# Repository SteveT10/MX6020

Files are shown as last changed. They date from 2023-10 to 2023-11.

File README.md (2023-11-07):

# MX60 + 20

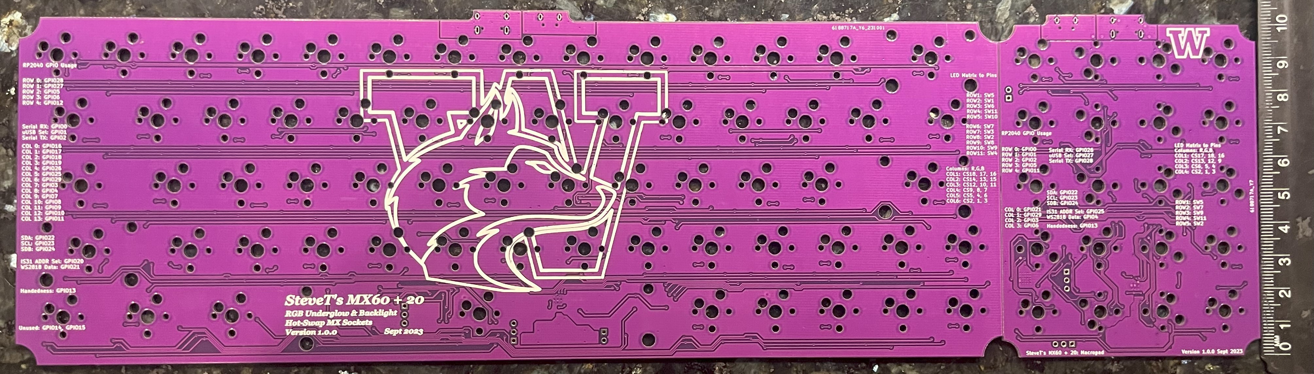
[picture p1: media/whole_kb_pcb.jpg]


The MX60 + 20 is a 60% keyboard PCB that features Hot-Swappable MX Switches, RGB underglow, RGB backlighting, and a dettachable 4x5 macropad via micro-usb male to male. The hardware was designed in Kicad by myself and uses QMK firwmare.

## Design Specifications:
Main body:
- Modified ANSI 60% layout
    - Shrank 2.25u shift down to 2u shift key.
    - Extra 1u key added on second to bottom row.
    - 64 Keys total.
- 8 WS2812 ARGBs for underglow
- 64 RGB Backlights
- USB-C Connecter to PC.
- Micro-USB Connecter to macropad.
- 288.8 mm by 104 mm PCB size.
- 2 Layer PCB

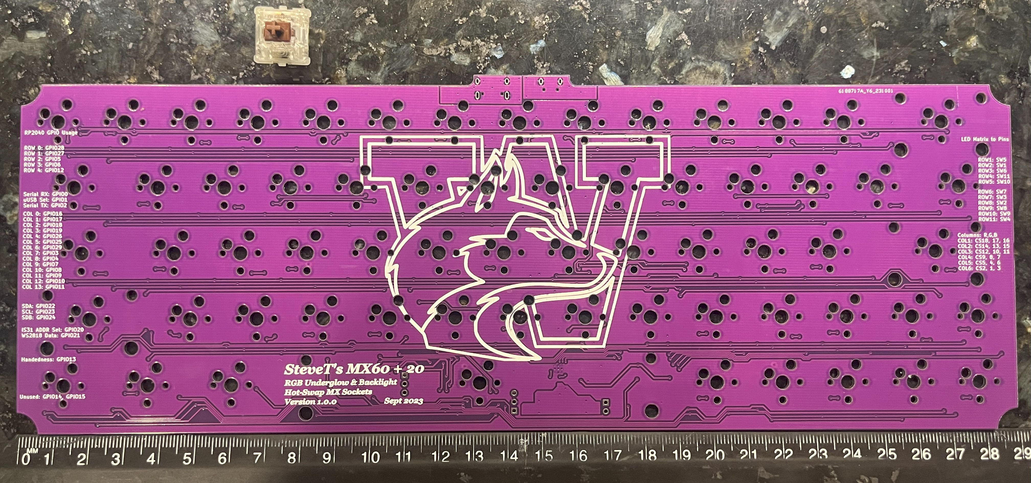
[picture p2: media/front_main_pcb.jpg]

Front side of main body PCB.

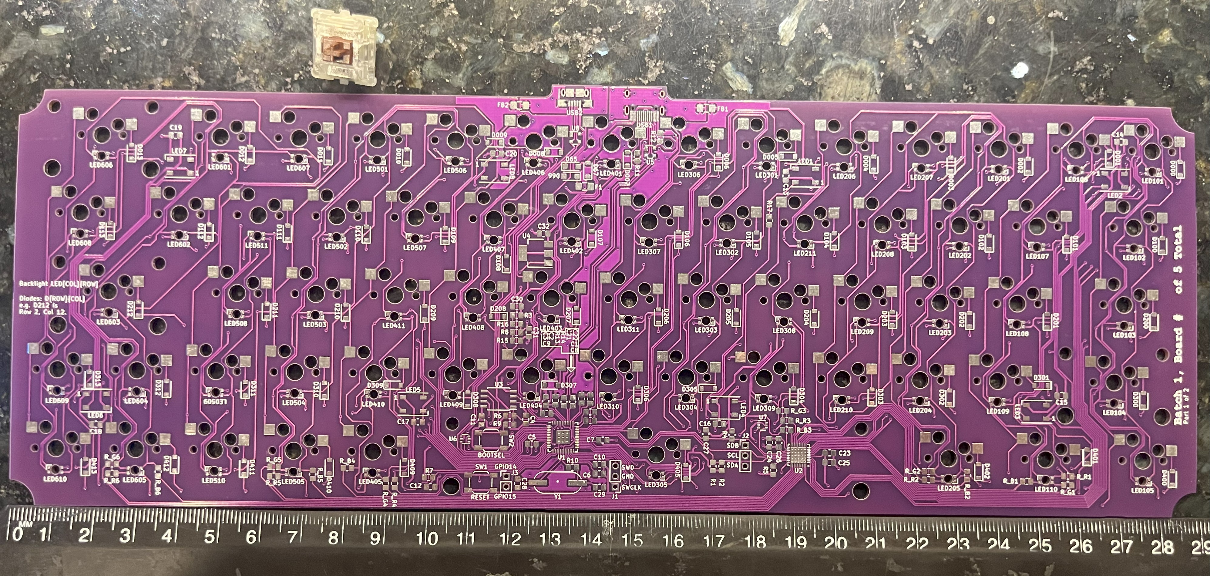
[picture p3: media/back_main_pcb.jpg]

Back side of main body PCB.

Macropad:
- 4x5 layout
    - 20 keys total.
- 4 WS2812 ARGBs for underglow.
- 20 RGB backlights.
- USB-C Connecter to PC.
- Micro-USB Connecter to main body.
- 79 mm by 104 mm PCB size.
- 2 Layer PCB

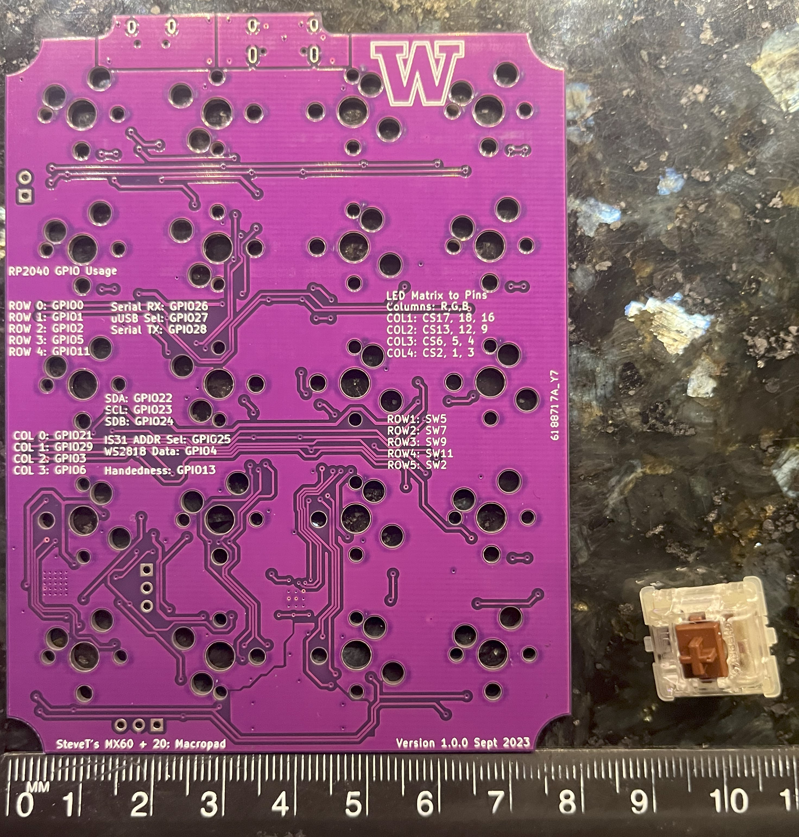
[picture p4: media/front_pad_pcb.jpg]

Front side of macro pad PCB.

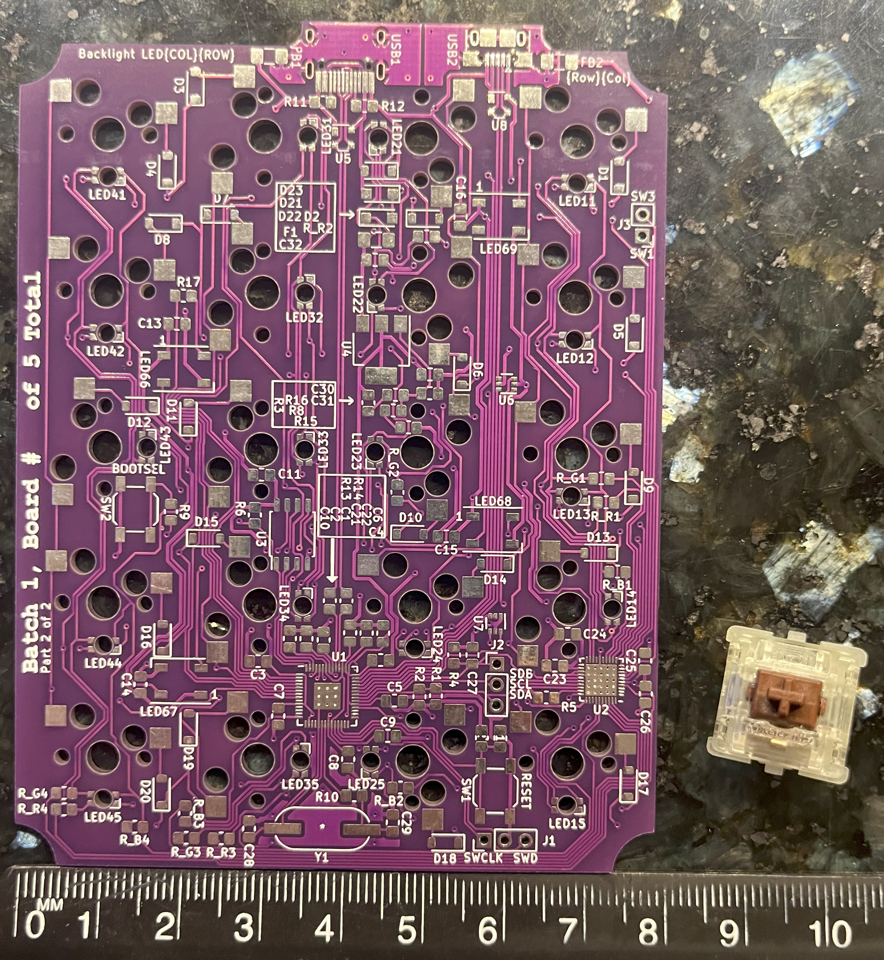
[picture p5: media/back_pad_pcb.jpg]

Back side of macro pad PCB.

## Goal
This project's overall goal is to act as a progressive learning project that complements my education in Computer Engineering. The first goal of this project was to familiarize myself with hardware design, where I would learn: 
- How to design circuit schematics and PCB layout in EDA software, specifically KiCad.
- How to use 3D printers and CAD software to design keycaps and cases
- How to use tools such reflow ovens, stencils, and soldering paste to assemble electronics.

<p>After verifying my hardware design and solving any potential issues, I would move onto the second goal of this project which is learn more about firmware, more specifically:</p>

- How to program C/Assembly in ARM-based MCU.
- How communication protocals such as I2C are implemented.
- More to come! (As I have not gotten to this stage yet)

## Creating Gerbers
Most PCB fabrication places expect gerber files. Gerber files describe the layout of pads, traces, drill holes, and other geometry for each layer on the PCB. Gerber files should be uploaded in a compress zip file containing all layers. To create gerber files in KiCad v7.0:

1. Open KiCad's PCB viewer
2. Go to `File` -> `Plot`
3. Select layers and options accordingly to your fabrication shop's settings. I chose JLCPCB so I set the following options below and set all others to unchecked.
    * Include Layers:
        * F.Cu
        * B.Cu
        * F.Paste
        * B.Paste
        * F.Silkscreen
        * B.Silkscreen
        * F.Mask
        * B.Mask
        * Edge.cuts
    * `Plot reference designators`
    * `Plot footprint values`
    * `Use Protel filename extensions`
    * `Subtract soldermask from silkscreen`
    * Check zone fills before plotting.
4. Set the output directory to `project-name-gerbers`, where project name is a placeholder.
5. Click `Plot` to generate layer gerbers.
6. Click `Generate Drill files...`
7. Again, select options that match with your fabrication shop's specifications. For JLCPCB, this is:
    * Drill File Format set to Excellon.
    * Oval Holes Drill Mode is set to `Use alternate drill mode`
    * Map File Format set to `Gerber`
    * Drill Origin set to `Absolute`
    * Drill units set to `Millimeters`
    * Zeros format set to `Decimal format`
8. Click `Generate Drill File`
9. Zip up your gerber files and now it is ready for upload.

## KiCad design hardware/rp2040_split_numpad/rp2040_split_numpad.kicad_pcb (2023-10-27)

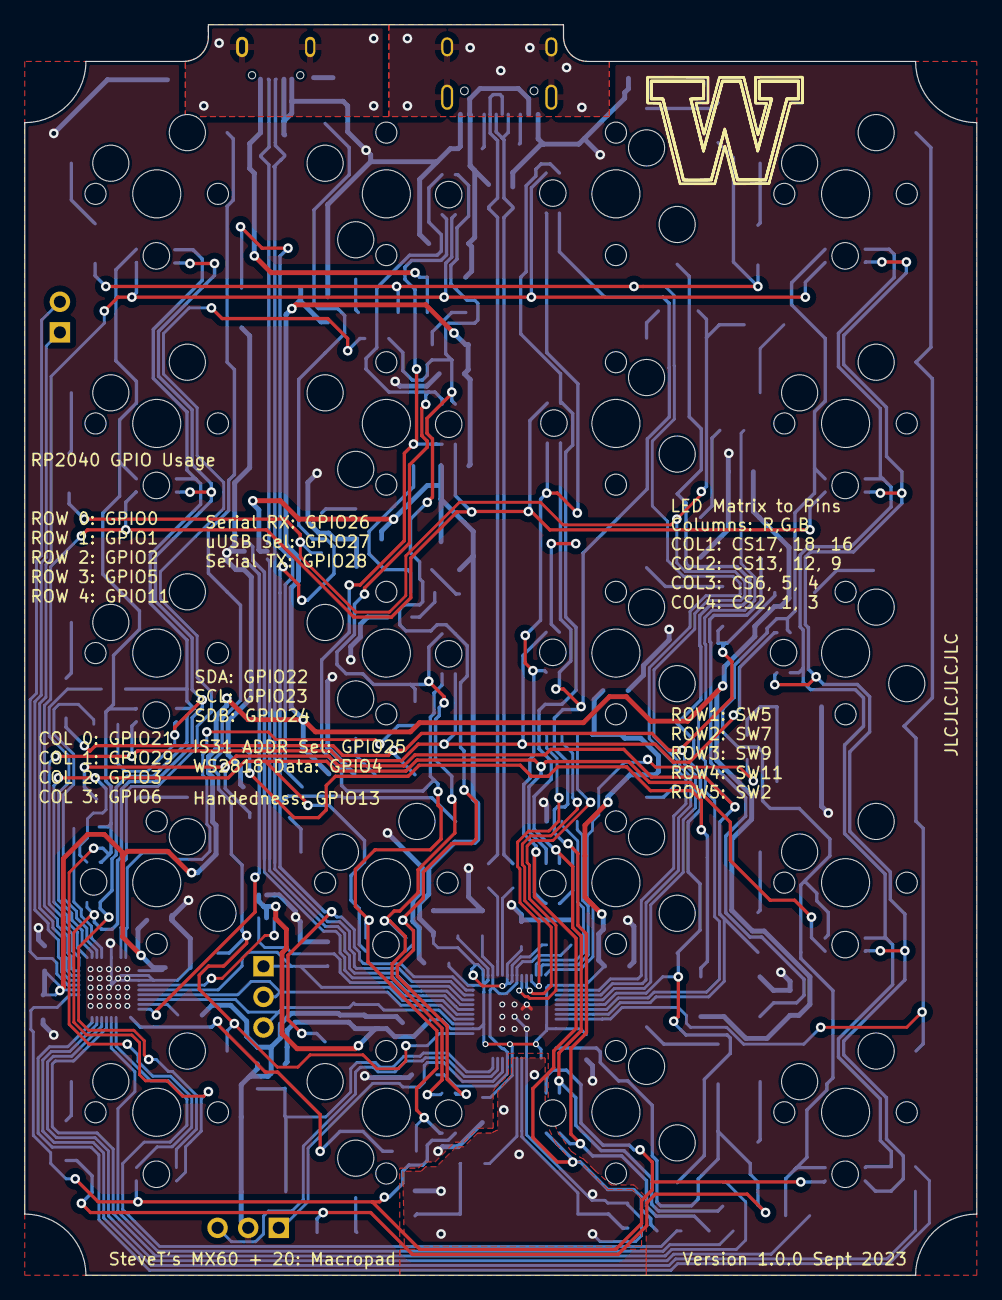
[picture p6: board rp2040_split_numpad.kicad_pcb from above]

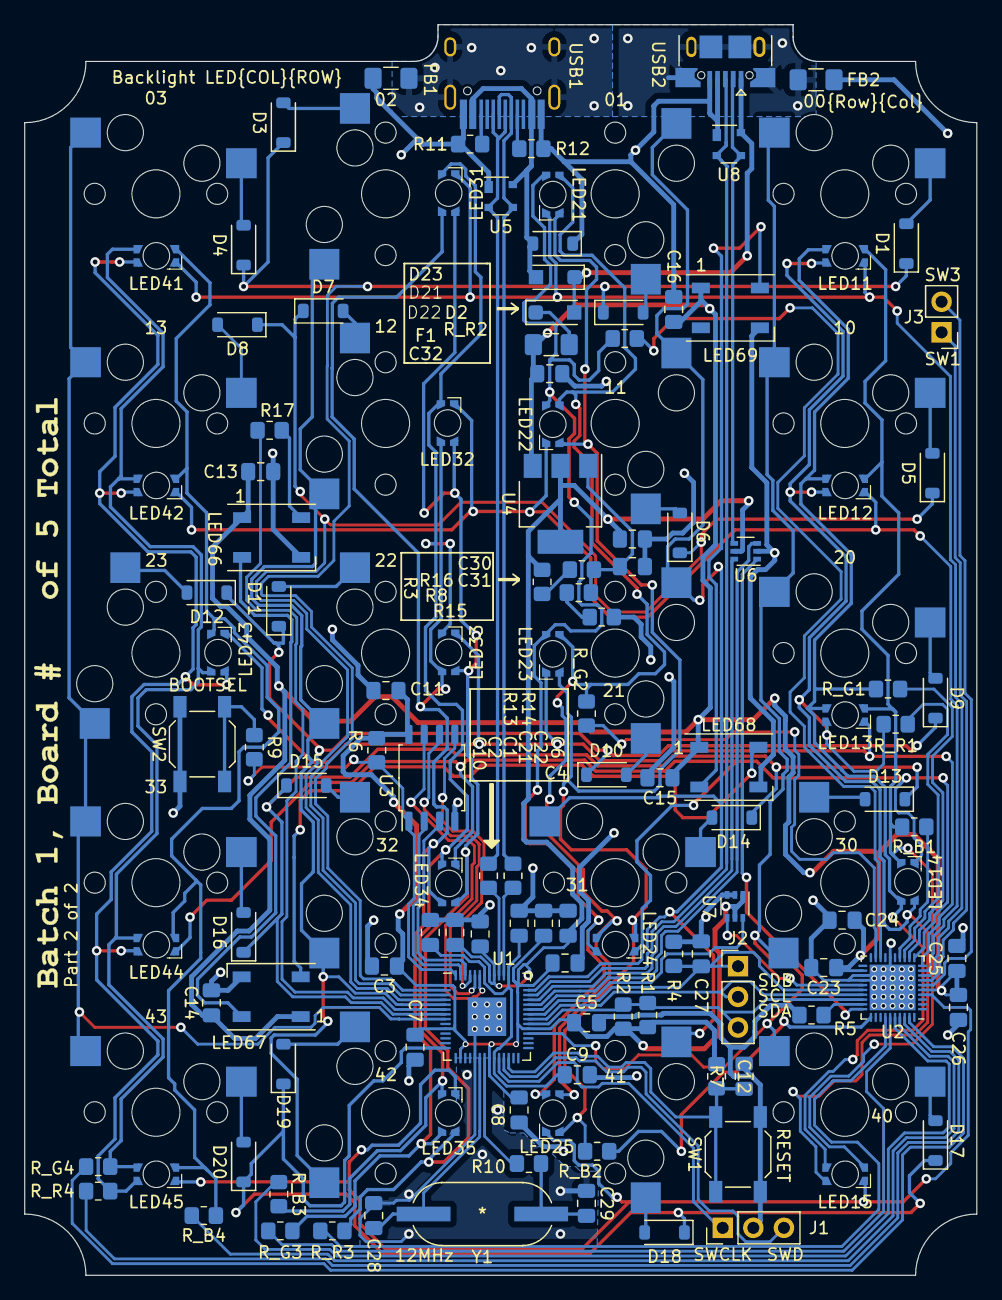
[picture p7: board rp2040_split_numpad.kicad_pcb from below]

Board: 2 copper layers, 79.0 x 103.8 mm, 143 parts (123 on the bottom side), 107 nets.

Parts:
C1, C2, C3, C4, C5, C6, C7, C8, C9, C10, C11, C12, C13, C14, C15, C16: 100n; C_0805_2012Metric_Pad1.18x1.45mm_HandSolder
C21, C22, C23, C24: 1u; C_0805_2012Metric_Pad1.18x1.45mm_HandSolder
C25, C26, C27: 0.1u; C_0805_2012Metric_Pad1.18x1.45mm_HandSolder
C28, C29: 27p; C_0805_2012Metric_Pad1.18x1.45mm_HandSolder
C30, C31, C32: 10u; C_0805_2012Metric_Pad1.18x1.45mm_HandSolder
D1, D2, D3, D4, D5, D6, D7, D8, D9, D10, D11, D12, D13, D14, D15, D16, D17, D18, D19, D20: D_Small; D_SOD-123
D21, D22: D_Schottky; D_SOD-123FL
D23: D_TVS; D_SOD-123
F1: 500m; Fuse_1206_3216Metric_Pad1.42x1.75mm_HandSolder
FB1, FB2: 60@100Mhz; L_1206_3216Metric_Pad1.42x1.75mm_HandSolder
J1, J2: Conn_01x03; PinHeader_1x03_P2.54mm_Vertical
J3: Conn_01x02; PinHeader_1x02_P2.54mm_Vertical
K1: 00; MXOnly-1U-Hotswap
K2: 01; MXOnly-1U-Hotswap
K3: 02; MXOnly-1U-Hotswap
K4: 03; MXOnly-1U-Hotswap
K5: 10; MXOnly-1U-Hotswap
K6: 11; MXOnly-1U-Hotswap
K7: 12; MXOnly-1U-Hotswap
K8: 13; MXOnly-1U-Hotswap
K9: 20; MXOnly-1U-Hotswap
K10: 21; MXOnly-1U-Hotswap
K11: 22; MXOnly-1U-Hotswap
K12: 23; MXOnly-1U-Hotswap
K13: 30; MXOnly-1U-Hotswap
K14: 31; MXOnly-1U-Hotswap
K15: 32; MXOnly-1U-Hotswap
K16: 33; MXOnly-1U-Hotswap
K17: 40; MXOnly-1U-Hotswap
K18: 41; MXOnly-1U-Hotswap
K19: 42; MXOnly-1U-Hotswap
K20: 43; MXOnly-1U-Hotswap
LED11, LED12, LED13, LED14, LED15, LED21, LED22, LED23, LED24, LED25, LED31, LED32, LED33, LED34, LED35, LED41, LED42, LED43, LED44, LED45: LED_RAGB; LED__RBG_1206_3216Metric_ReverseMount_Hole2.2x2.2mm
LED66, LED67, LED68, LED69: WS2812B; LED_WS2812B_PLCC4_5.0x5.0mm_P3.2mm
R1, R2, R3: 2k; R_0805_2012Metric_Pad1.20x1.40mm_HandSolder
R4: 100k; R_0805_2012Metric_Pad1.20x1.40mm_HandSolder
R5, R6, R7: 10k; R_0805_2012Metric_Pad1.20x1.40mm_HandSolder
R8, R9, R10: 1k; R_0805_2012Metric_Pad1.20x1.40mm_HandSolder
R11, R12: 5.1k; R_0805_2012Metric_Pad1.20x1.40mm_HandSolder
R13, R14: 27; R_0805_2012Metric_Pad1.20x1.40mm_HandSolder
R15, R16, R17: 500; R_0805_2012Metric_Pad1.20x1.40mm_HandSolder
R_B1, R_B2, R_B3, R_B4: 20; R_0805_2012Metric_Pad1.20x1.40mm_HandSolder
R_G1, R_G2, R_G3, R_G4: 20; R_0805_2012Metric_Pad1.20x1.40mm_HandSolder
R_R1, R_R2, R_R3, R_R4: 51; R_0805_2012Metric_Pad1.20x1.40mm_HandSolder
SW1: Reset; SW_SPST_SKQG_WithStem
SW2: Boot; SW_SPST_SKQG_WithStem
U1: RP2040; QFN-56-1EP_7x7mm_P0.4mm_EP3.2x3.2mm
U2: IS31FL3743A-QULS4-TR; UQFN-40-1EP_5x5mm_P0.4mm_EP3.8x3.8mm
U3: W25Q32JVSS; SOIC-8_5.23x5.23mm_P1.27mm
U4: NCP1117-ADJ_SOT223; SOT-223-3_TabPin2
U5, U8: PRTR5V0U2X; SOT-143
U6, U7: BL1551B; SOT-363_SC-70-6
USB1: HRO-TYPE-C-31-M-12; HRO-TYPE-C-31-M-12-HandSoldering
USB2: USB_B_Micro; USB_Micro-B_XKB_U254-051T-4BH83-F1S
Y1: 12MHz; ABLS-12.000MHZ-B4-T

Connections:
+1V1: C9.1, C10.1, C21.1, U1.23 (DVDD), U1.45 (VREG_VOUT), U1.50 (DVDD)
+3.3V: C1.1, C2.1, C3.1, C4.1, C5.1, C6.1, C7.1, C8.1, C11.1, C22.1, C30.1, R1.1, R2.1, R3.1, R6.1, R7.1, U1.1 (IOVDD), U1.10 (IOVDD), U1.16 (GPIO13), U1.22 (IOVDD), U1.33 (IOVDD), U1.42 (IOVDD), U1.43 (ADC_AVDD), U1.44 (VREG_IN), U1.48 (USB_VDD), U1.49 (IOVDD), U3.8 (VCC), U4.2 (VO), U6.5 (V+), U7.1, U7.5 (V+)
+5V: C13.1, C14.1, C15.1, C16.1, C23.1, C24.1, C25.1, C26.1, C32.1, F1.2, LED66.1 (VDD), LED67.1 (VDD), LED68.1 (VDD), LED69.1 (VDD), U2.5 (PVCC), U2.22 (VCC), U4.3 (VI)
ADDR1: U2.25 (ADDR1), U7.4
ADDR_SEL: U1.37 (GPIO25), U7.6
BLUE1: R_B1.1, U2.14 (CS16)
BLUE2: R_B2.1, U2.31 (CS9)
BLUE3: R_B3.1, U2.36 (CS4)
BLUE4: R_B4.1, U2.37 (CS3)
COL0: K1.2, K5.2, K9.2, K13.2, K17.2, U1.32 (GPIO21)
COL1: K2.2, K6.2, K10.2, K14.2, K18.2, U1.41 (GPIO29_ADC3)
COL2: K3.2, K7.2, K11.2, K15.2, K19.2, U1.5 (GPIO3)
COL3: K4.2, K8.2, K12.2, K16.2, K20.2, U1.8 (GPIO6)
D+: R13.2, U5.2 (I/O1), USB1.6 (DP1), USB1.8 (DP2)
D-: R14.1, U5.3 (I/O2), USB1.5 (DN2), USB1.7 (DN1)
Earth: FB1.1, USB1.13 (SHIELD)
GND: C1.2, C2.2, C3.2, C4.2, C5.2, C6.2, C7.2, C8.2, C9.2, C10.2, C11.2, C12.2, C13.2, C14.2, C15.2, C16.2, C21.2, C22.2, C23.2, C24.2, C25.2, C26.2, C27.2, C28.1, C29.1, C30.2, C31.2, C32.2, D23.1 (A1), FB1.2, FB2.2, J1.2, LED66.3 (VSS), LED67.3 (VSS), LED68.3 (VSS), LED69.3 (VSS), R4.2, R5.2, R11.2, R12.2, R15.2, SW1.2, SW2.1, U1.19 (TESTEN), U1.57 (GND), U2.16 (PGND), U2.23 (AGND), U2.24 (ADDR2), U2.41 (Thermal), U3.4 (GND), U5.1 (GND), U6.2 (GND), U7.2 (GND), U7.3, U8.1 (GND), USB1.1 (GND), USB1.12 (GND), USB2.4 (ID), USB2.5 (GND)
GND1: FB2.1, USB2.6 (Shield)
GREEN1: R_G1.1, U2.12 (CS18)
GREEN2: R_G2.1, U2.19 (CS12)
GREEN3: R_G3.1, U2.35 (CS5)
GREEN4: R_G4.1, U2.39 (CS1)
LED_ROW1: LED11.2 (A), LED21.2 (A), LED31.2 (A), LED41.2 (A), U2.8 (SW5)
LED_ROW2: LED12.2 (A), LED22.2 (A), LED32.2 (A), LED42.2 (A), U2.9 (SW7)
LED_ROW3: LED13.2 (A), LED23.2 (A), LED33.2 (A), LED43.2 (A), U2.10 (SW9)
LED_ROW4: LED14.2 (A), LED24.2 (A), LED34.2 (A), LED44.2 (A), U2.11 (SW11)
LED_ROW5: LED15.2 (A), LED25.2 (A), LED35.2 (A), LED45.2 (A), U2.4 (SW2)
unnamed: C29.2, R10.1, Y1.1
unnamed: D1.2 (A), K1.1
unnamed: D2.2 (A), K2.1
unnamed: D3.2 (A), K3.1
unnamed: D4.2 (A), K4.1
unnamed: D5.2 (A), K5.1
unnamed: D6.2 (A), K6.1
unnamed: D7.2 (A), K7.1
unnamed: D8.2 (A), K8.1
unnamed: D9.2 (A), K9.1
unnamed: D10.2 (A), K10.1
unnamed: D11.2 (A), K11.1
unnamed: D12.2 (A), K12.1
unnamed: D13.2 (A), K13.1
unnamed: D14.2 (A), K14.1
unnamed: D15.2 (A), K15.1
unnamed: D16.2 (A), K16.1
unnamed: D17.2 (A), K17.1
unnamed: D18.2 (A), K18.1
unnamed: D19.2 (A), K19.1
unnamed: D20.2 (A), K20.1
unnamed: D22.1 (K), F1.1
unnamed: J3.1, U2.7 (SW3)
unnamed: J3.2, U2.6 (SW1)
unnamed: LED11.4 (BK), LED12.4 (BK), LED13.4 (BK), LED14.4 (BK), LED15.4 (BK), R_B1.2
unnamed: LED11.3 (GK), LED12.3 (GK), LED13.3 (GK), LED14.3 (GK), LED15.3 (GK), R_G1.2
unnamed: LED11.1 (RK), LED12.1 (RK), LED13.1 (RK), LED14.1 (RK), LED15.1 (RK), R_R1.2
unnamed: LED21.4 (BK), LED22.4 (BK), LED23.4 (BK), LED24.4 (BK), LED25.4 (BK), R_B2.2
unnamed: LED21.3 (GK), LED22.3 (GK), LED23.3 (GK), LED24.3 (GK), LED25.3 (GK), R_G2.2
unnamed: LED21.1 (RK), LED22.1 (RK), LED23.1 (RK), LED24.1 (RK), LED25.1 (RK), R_R2.2
unnamed: LED31.4 (BK), LED32.4 (BK), LED33.4 (BK), LED34.4 (BK), LED35.4 (BK), R_B3.2
unnamed: LED31.3 (GK), LED32.3 (GK), LED33.3 (GK), LED34.3 (GK), LED35.3 (GK), R_G3.2
unnamed: LED31.1 (RK), LED32.1 (RK), LED33.1 (RK), LED34.1 (RK), LED35.1 (RK), R_R3.2
unnamed: LED41.4 (BK), LED42.4 (BK), LED43.4 (BK), LED44.4 (BK), LED45.4 (BK), R_B4.2
unnamed: LED41.3 (GK), LED42.3 (GK), LED43.3 (GK), LED44.3 (GK), LED45.3 (GK), R_G4.2
unnamed: LED41.1 (RK), LED42.1 (RK), LED43.1 (RK), LED44.1 (RK), LED45.1 (RK), R_R4.2
unnamed: LED66.4 (DIN), R17.1
unnamed: LED66.2 (DOUT), LED67.4 (DIN)
unnamed: LED67.2 (DOUT), LED68.4 (DIN)
unnamed: LED68.2 (DOUT), LED69.4 (DIN)
unnamed: R9.1, SW2.2
unnamed: R8.2, R15.1
unnamed: R3.2, R16.1
unnamed: R5.1, U2.29 (ISET)
unnamed: C31.1, R8.1, R16.2, U4.1 (ADJ)
unnamed: R12.1, USB1.4 (CC1)
unnamed: R11.1, USB1.10 (CC2)
QSPI_CLK: U1.52 (QSPI_SCLK), U3.6 (CLK)
QSPI_SD1: U1.55 (QSPI_SD1), U3.2 (DO(IO1))
QSPI_SD2: U1.54 (QSPI_SD2), U3.3 (IO2)
QSPI_SD3: U1.51 (QSPI_SD3), U3.7 (IO3)
QSPI_SDO: U1.53 (QSPI_SD0), U3.5 (DI(IO0))
QSPI_SS: R6.2, R9.2, U1.56 (QSPI_SS), U3.1 (~CS)
RED1: R_R1.1, U2.13 (CS17)
RED2: R_R2.1, U2.18 (CS13)
RED3: R_R3.1, U2.34 (CS6)
RED4: R_R4.1, U2.38 (CS2)
RGB_DI: R17.2, U1.6 (GPIO4)
ROW0: D1.1 (K), D2.1 (K), D3.1 (K), D4.1 (K), U1.2 (GPIO0)
ROW1: D5.1 (K), D6.1 (K), D7.1 (K), D8.1 (K), U1.3 (GPIO1)
ROW2: D9.1 (K), D10.1 (K), D11.1 (K), D12.1 (K), U1.4 (GPIO2)
ROW3: D13.1 (K), D14.1 (K), D15.1 (K), D16.1 (K), U1.7 (GPIO5)
ROW4: D17.1 (K), D18.1 (K), D19.1 (K), D20.1 (K), U1.14 (GPIO11)
Reset: C12.1, R7.2, SW1.1, U1.26 (RUN)
SCL: J2.2, U1.35 (GPIO23), U2.27 (SCL)
SDA: J2.3, R1.2, R2.2, U1.34 (GPIO22), U2.28 (SDA)
SDB: C27.1, J2.1, R4.1, U1.36 (GPIO24), U2.26 (SDB)
SERIAL_RX: U1.38 (GPIO26_ADC0), U6.3
SWCLK: J1.1, U1.24 (SWCLK)
SWD: J1.3, U1.25 (SWD)
SYNC: U2.30 (SYNC), U6.1
USB_DM: R14.2, U1.46 (USB_DM)
USB_DP: R13.1, U1.47 (USB_DP)
VCC: D21.2 (A), D23.2 (A2), U5.4 (VCC), USB1.2 (VBUS), USB1.11 (VBUS)
VSYS: D21.1 (K), D22.2 (A), U8.4 (VCC), USB2.1 (VBUS)
XIN: C28.2, U1.20 (XIN), Y1.2
XOUT: R10.2, U1.21 (XOUT)
uUSB_D+: U1.40 (GPIO28_ADC2), U8.2 (I/O1), USB2.3 (D+)
uUSB_D-: U6.4, U8.3 (I/O2), USB2.2 (D-)
uUSB_SEL: U1.39 (GPIO27_ADC1), U6.6

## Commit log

2023-10-27 First commit: KiCad Files, README, media images
    [key_matrix.kicad_sch, leds.kicad_sch, rp2040_split_main.kicad_sch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]
2023-12-18 Fixed Vreg circuit and silkscreen
    [rp2040_split_main.kicad_sch]

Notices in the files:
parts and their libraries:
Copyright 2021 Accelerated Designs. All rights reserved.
